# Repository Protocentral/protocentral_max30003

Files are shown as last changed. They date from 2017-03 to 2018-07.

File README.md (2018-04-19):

# ProtoCentral MAX30003 Single-lead ECG Breakout Board

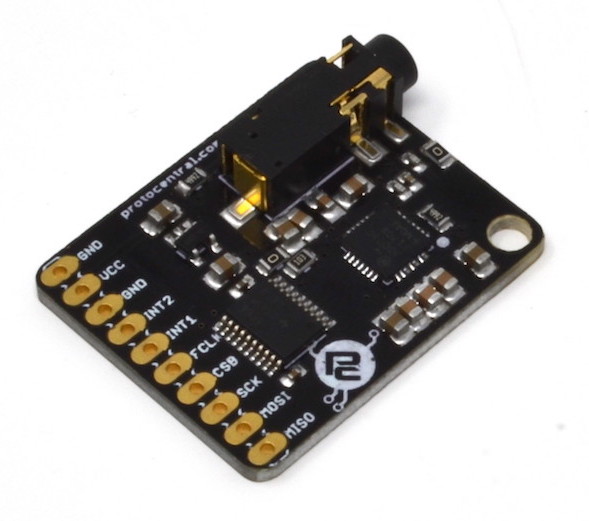
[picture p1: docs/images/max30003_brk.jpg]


If you dont already have one, you can buy [ProtoCentral MAX30003 breakout here.](https://www.protocentral.com/open-medical-devices/1149-protocentral-max30003-single-lead-ecg-breakout-board.html)

MAX30003 is a single-lead ECG monitoring IC which has built-in R-R detection and several other features that make it perfect for a wearable single-lead ECG application.  

Several new features on this chip make it ideal for wearable applications. First is the low power consumption - just 85 uW of power and can work from 1.1 V onwards ! Also of interest is the fact that it can work with only two chest electrodes without the need for a third right-leg drive (DRL) electrode.

The best feature of this chip though is the built-in R-R detection algorithm which can measure the time between successive peaks of the QRS complex of the ECG. This means that heart-computation comes right out of the box without any microcontroller-side code requirement. Heart-rate computation just got a lot easier !!

# Features

* MAX30003 IC on-board
* Single-lead ECG monitoring
* R-R peak detection for heart rate computation
* High DC Offset range
* Heart Rate computation using Pan-Tompkins algorithm
* On-board level translator for 5V-tolerant operation
* On-board low-noise 1.8V and 3.3V voltage regulator

# What's included

* ProtoCentral MAX30003 Breakout board
* Straight pin headers
* 2-electrode ECG connector with stereo connector
* 10x disposable ECG stick-on electrodes

# Repository Contents

* **/software** - Arduino library and example sketches.
* **/hardware** - All Eagle hardware design files
* **/docs** - additional documentation

# Wiring the board to your Arduino

If you have bought the breakout the connection with the Arduino board is as follows:

|MAX30003 pin label| Arduino Connection |Pin Function |
|--- |:---:|---:|
| MISO | D12 |  Slave out| 
| MOSI | D11 |  Slave in |
| SCK | D13 |  Serial clock |
| CS0 | D7 |  Slave select|
| FCLK | D6 |  External clock(32KHz) |
| INT1 | NC |  Interrupt |
| INT2 | NC |  Interrupt |
| 3V3 | Supply |  Board which supports 3.3V and 1.8V |
| VCC | Supply 5V | 5V |
| GND | Gnd  

# Running the Arduino Sketch

If you have correctly installed the libraries, the example sketeches should now be available from within Arduino.

[Download the Arduino Sketch here for this board here.](https://github.com/Protocentral/protocentral_max30003/releases/download/v0.1/protocentral_max30003_arduino.zip)

Open up your Arduino IDE and run the Arudino sketch (.ino) file in the archive that you downloaded. Your Arduino should now be programmed to read the ecg data and sending over the USB-UART.  

# Using the ProtoCentral MAX30003 GUI

The GUI for visulizing the ECG data as well as parameters like R-R interval and Heartrate is written in Processing, based on Java and is cross-compilable across platforms.

Java 8 is required on all platforms for running the processing-based GUI application. You can download Java for your platform from the following link.

[https://java.com/en/download/](https://java.com/en/download/)

## Processing GUI Installation

Download the zip file containing the executable files from the following links for 32-bit/64-bit Windows. If you do not know if you have a 64-bit or 32-bit computer, please download the 32-bit version.

* [Windows 32-bit Executable (ZIP)](https://github.com/Protocentral/protocentral_max30003/releases/download/v0.1/protocentral_max30003_gui-v0.1-win32.zip)
* [Windows 64-bit Executable (ZIP)](https://github.com/Protocentral/protocentral_max30003/releases/download/v0.1/protocentral_max30003_gui-v0.1-win64.zip/healthypi_gui_win64.zip)
* [MacOS Executable (ZIP)](https://github.com/Protocentral/protocentral_max30003/releases/download/v0.1/protocentral_max30003_gui-v0.1-macOS.zip)
* [Linux 32-bit Executable (ZIP)](https://github.com/Protocentral/protocentral_max30003/releases/download/v0.1/protocentral_max30003_gui-v0.1-linux32.zip)
* [Linux 64-bit Executable (ZIP)](https://github.com/Protocentral/protocentral_max30003/releases/download/v0.1/protocentral_max30003_gui-v0.1-linux64.zip)
* [Raspberry Pi - Raspbian (ZIP)](https://github.com/Protocentral/protocentral_max30003/releases/download/v0.1/protocentral_max30003_gui-v0.1-linuxARM.zip)

Simply download the appropriate file for your operating system, unzip the contents and run the executable program contained in it.

Select the port to which your Arduino is connected to from the "Select Port" dropdown box and data should immedaitely start coming in.

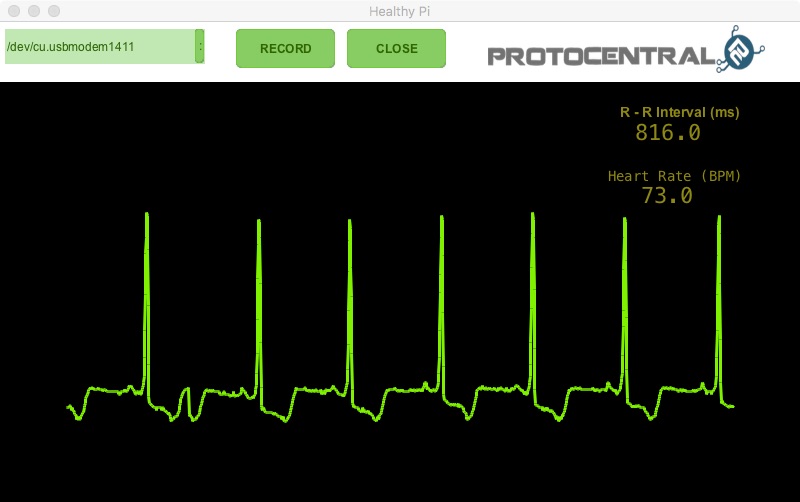
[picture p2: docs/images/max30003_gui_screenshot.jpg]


# Connecting the ECG Electrodes

A 2-electrode cable along with a standard stereo jack is provided along with the shield to connect the electrodes to the board. The electrode input connector is highlighted in the below picture.

The other side of the electrode connector would connect to snap-on electrodes attached to the body. For testing purposes, you can use an ECG simulator to provide inputs to the board.

*Warning:
When connecting the electodes to the body, it is safer to disconnect the mains power source to the Arduino. For example, if  you are using the Arduino along with a laptop, disconnecting the battery charger from the laptop would be a safe option.*

# Placing the Electrodes on the body

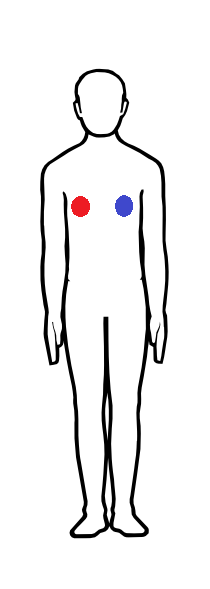
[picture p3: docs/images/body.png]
Wearing the Electrode


# License Information

This product is open source! Both, our hardware and software are open source and licensed under the following licenses:

## Hardware

**All hardware is released under [Creative Commons Share-alike 4.0 International](http://creativecommons.org/licenses/by-sa/4.0/).**


You are free to:

* Share — copy and redistribute the material in any medium or format
* Adapt — remix, transform, and build upon the material for any purpose, even commercially.
The licensor cannot revoke these freedoms as long as you follow the license terms.

Under the following terms:

* Attribution — You must give appropriate credit, provide a link to the license, and indicate if changes were made. You may do so in any reasonable manner, but not in any way that suggests the licensor endorses you or your use.
* ShareAlike — If you remix, transform, or build upon the material, you must distribute your contributions under the same license as the original.

## Software

**All software is released under the MIT License(http://opensource.org/licenses/MIT).**

THE SOFTWARE IS PROVIDED "AS IS", WITHOUT WARRANTY OF ANY KIND, EXPRESS OR IMPLIED, INCLUDING BUT NOT LIMITED TO THE WARRANTIES OF MERCHANTABILITY, FITNESS FOR A PARTICULAR PURPOSE AND NONINFRINGEMENT. IN NO EVENT SHALL THE AUTHORS OR COPYRIGHT HOLDERS BE LIABLE FOR ANY CLAIM, DAMAGES OR OTHER LIABILITY, WHETHER IN AN ACTION OF CONTRACT, TORT OR OTHERWISE, ARISING FROM, OUT OF OR IN CONNECTION WITH THE SOFTWARE OR THE USE OR OTHER DEALINGS IN THE SOFTWARE.

Please check [*LICENSE.md*](LICENSE.md) for detailed license descriptions.

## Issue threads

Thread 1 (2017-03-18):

Incorrect filter settings

protocentralashwin, 2017-03-18:
LPF, HPF filter settings to be updated

protocentralashwin, 2017-05-06:
Fixed

Closed 2017-05-06.

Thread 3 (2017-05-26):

Runing on arduino

ALEXRG27, 2017-05-26:
I'm trying to read the register with the value of the R_R , but I can't read anything, I get this :
ú            0,0,0,,0

     Serial.print(RTOR_msb);
     Serial.print(",");
     Serial.print(RTOR_lsb);
     Serial.print(",");
     Serial.print(rtor);
     Serial.print(",");
     //Serial.print(rr);
     Serial.print(",");
     Serial.println(HR);
How can I Read the ECG value from the arduino?
I also have a problem with the code, when i compile it says:
sketch\MAX30003.h:28:0: warning: "NO_OP" redefined

 #define   NO_OP           0x7F

 ^

sketch\MAX30003.h:9:0: note: this is the location of the previous definition

 #define   NO_OP           0x00

VenkateshBhat, 2017-05-27:
Dear Alex,

- Are you able to see the waveform on the gui?, could you attach the screenshot?
- If the data is clean these registers rr and HR will hold the corresponding values.
- NO_OP register doesn't have any impact on the operation, the warning can be ignored.
- Please ensure that you have the latest version of Arduino IDE

ALEXRG27, 2017-05-29:
No I can't see anything->
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

ALEXRG27, 2017-05-29:
If i disconect the board, i get this :
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
So the board i getting something but I don't know why i can't read the pulse

VenkateshBhat, 2017-05-29:
Thanks for sharing, are you sure about the wiring connections?,  do check with the latest version of Arduino IDE -- http://www.arduino.org/downloads

VenkateshBhat, 2017-05-29:
Please attach the picture of Hardware setup too.

ALEXRG27, 2017-06-07:
I've checked my board and all seems to be good. I used the same layout as you.

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

VenkateshBhat, 2017-06-21:
Have you made any progress on this?, it seems to be fuss in the assembly.

ALEXRG27, 2017-06-23:
No, I've tested the whole board and everything seems fine, i'll test it on my final design without the arduino I wish I could  read the data from the sensor.

DJMBurkhard, 2017-09-27:
Hello,
I have two questions:

1.) Connecting the max30003 board with Arduino Uno:
Should I use the 3V or the 5V?
I assume it is the one or the other?
And the power is supplied via the computer? (I am using a MAC)

2.) I cannot upload the sketch to Arduino
I receive the message:
fatal error: TimerOne.h: No such file or directory
#include <TimerOne.h>

Where can I find this file? It seems to be missing?
It is not in the folder,
I see the MAX30003.h  only -

DJMBurkhard, 2017-09-29:
Thanks for your previous respond which helped and could get:
The graph I receive now, using processing is the attached image
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

- the BPM are jumping around between 3 and 60, around 60, that would be correct, but it is jumping everywhere and:
- the graph is much different to what you show in the manual, see above image
-  the cvs file contains just one symbol - no data.
- I am told that the " protocentral_max30003_gui.app" is defect, and should take it to the trash.

Closed 2017-09-28.

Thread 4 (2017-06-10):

Analog voltage differences

fzldmn, 2017-06-10:
Hello in datasheet  recommended analog voltage is max 2V.
But in your design u used 3.3V

Will it be a problem for getting
 stable measurements.

VenkateshBhat, 2017-06-21:
Yes, the recommended power supply voltage is 1.1V - 2V , we tested for the long duration and there is no heating as such. We are getting the stable readings.

DJMBurkhard, 2017-09-27:
Hello,

1. Connecting the max30003 board with Arduino Uno:
    Should I use the 3V or the 5V?
    I assume it is one or the other? And the power is supplied via the computer (I am using a MAC)

2.   I cannot  upload the sketch to Arduino
    I receive the message:
   fatal error: TimerOne.h: No such file or directory
   #include <TimerOne.h>

    Where can I find this file? It seems to be missing.

VenkateshBhat, 2017-09-28:
@DJMBurkhard
1. Connect to 5V if you are using Arduino Uno.
2. Install the library externally for TimerOne.h
Go to sketch->Include libray -> Manage libraries
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

Closed 2017-10-09.

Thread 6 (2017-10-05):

BPM and Graphic with Processing strange

DJMBurkhard, 2017-10-05:
The graph I receive now, using processing is the attached image:
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

- the BPM are jumping around between 3 and 60, around 60, that would be correct, but it is jumping everywhere and:
- the graph is much different to what you show in the manual, see above image
-  the cvs file contains just one symbol - no data.
- I am told that the " protocentral_max30003_gui.app" is defect, and should take it to the trash.

VenkateshBhat, 2017-10-05:
@DJMBurkhard
Thanks for the feedback, the signal is too erratic.
ensure:
 > there is a good contact of electrodes on body
 > have a latest version of the Arduino(1.6.11 or above)
 >  Remove the power adapter from the PC/laptop and check

I will check on the no data on .csv file and get back to you.

DJMBurkhard, 2017-10-05:
Thank you -

So far, these issues are under control,
- I have the latest Arduino installed, 1.8.4,
- the electrodes are new and were placed as described,
- the power adapter was not plugged in while the trying to take measurement
( I am using a mac book air)
I am not aware of any other possible disturbing equipment
nearby:

In fact, before, I had taken measurements with another peace of equipment ,
"the pulse sensor", which is just wrapped around the finger.
That worked fine, as along as I was not moving.

But my hope is still in protocentral_max 30003, and I expect it to be more accurate.
However, as said before,  the BPM is mainly far too low,
at 3 to 30, rarely  around 60, which would be normal.

So, if you have any other idea, that would be much appreciated -

On 5. Oct 2017, at 16:16, Venkatesh Bhat <notifications@github.com> wrote:

@DJMBurkhard <https://github.com/djmburkhard>
Thanks for the feedback, the signal is too erratic.
ensure:

there is a good contact of electrodes on body
have a latest version of the Arduino(1.6.11 or above)
Remove the power adapter from the PC/laptop and check

I will check on the no data on .csv file and get back to you.

—
You are receiving this because you were mentioned.
Reply to this email directly, view it on GitHub <https://github.com/Protocentral/protocentral_max30003/issues/6#issuecomment-334478341>, or mute the thread <https://github.com/notifications/unsubscribe-auth/Ae2F-fV0dbb-21FV76LphRHGAeUkDdchks5spOSpgaJpZM4PupwZ>.

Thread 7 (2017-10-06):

Design

amir1994a, 2017-10-06:
In page 44 of the datasheet of max30003, in the recommended circuit it has used 1k resistor while you have
used 49.9k resistor? is this because of a particular reason? what will happen if you use a 1k resistor instead of 49.9k?

VenkateshBhat, 2017-10-07:
@amir1994a ,
the diagram mentioned in the datasheet is a typical application circuit not the recommended values.  The RC filter here acts as an anti-aliasing filter .Reference diagram is here https://www.maximintegrated.com/en/design/tools/appnotes/6312/MAXREFDES100_SCH_RA.pdf

amir1994a, 2017-10-07:
thank you, what about the zero value resistor?is it going to be a problem if we don't use them?

VenkateshBhat, 2017-10-07:
No, it does not affect the performance.

Tomisdebom, 2021-09-13:
> @amir1994a ,
> the diagram mentioned in the datasheet is a typical application circuit not the recommended values. The RC filter here acts as an anti-aliasing filter .Reference diagram is here https://www.maximintegrated.com/en/design/tools/appnotes/6312/MAXREFDES100_SCH_RA.pdf

Wait, the reference design you just posted is different than the schematics that are in the Github repo. Are you sure your reference design corresponds to the Protocentral board?

Closed 2017-10-09.

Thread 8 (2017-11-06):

A question about the external clock

amir1994a, 2017-11-06:
Hi, I've been trying to understand the board and the code, I'm confused a little bit.
How do you produce the external clock?it seems that there is no crystal or oscillator on the board.
what is this line for?:
    digitalWrite( CLK_PIN, digitalRead(CLK_PIN ) ^ 1 ); // toggle Digital6 attached to FCLK  of MAX30003

why do toggle the fclk pin?

VenkateshBhat, 2017-11-06:
@amir1994a
Thanks for the comment,
Since Arduino doesnot have internal RTC we are deriving using the timer with 64KHz clock frequency and toggling a GPIO.

amir1994a, 2017-11-06:
Thank you for your answer, at first my code(yours actually) wouldn't compile because of the lack of time1 library, i downloaded it from this link(9th version) and it compiled without error, is that the right procedure?

one more question, actually, i did not use your board because i couldn't find it in my country, so i tried to use your schematic and make it myself. only i did not use 0-ohm resistors. and i did not use ground plane(except for the ic pad). and i used this voltage converter:

https://www.sparkfun.com/products/12009

my board did not work, i assumed that maybe this voltage converter is not good for spi connection and maybe 5 and 1.8 have a lot difference for my voltage converter.
I'm really frustrated and i know that only you can help me.
will you please help me a little bit?
(also the ac line frequency is 50hz in my country and is different from 60hz of some countries i don't know that this will cause any problem or not)

Thanks a million
please help me!!!

VenkateshBhat, 2017-11-07:
@amir1994a ,
Do not worry we are here to help you out!
Could you please share your design? what signal are you getting at the output? FCLK is critical are you sure about the signal? the level converter could not be the problem, BSS138 is good enough.

amir1994a, 2017-11-07:
Hi, thank you, you are so kind.
Actually, I get no signal at the output.
I have attached a pdf file of my schematic and PCB, I'll be grateful f you check it out. it is a little bit messy!
Can you explain a little bit about TimerOne library?, because arduino does not seem to have this library by default.
I'll be thankful if you tell me what my problem is.
[heart.PDF](https://github.com/Protocentral/protocentral_max30003/files/1448888/heart.PDF)

amir1994a, 2017-11-12:
Hi there,
I was wondering whether you had the time to look at my previous question.
I'm enthusiastically looking forward to hearing from you

protocentralashwin, 2018-04-06:
Merging this with issue #13

Closed 2018-04-06.

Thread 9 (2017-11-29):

Ecg circuit

amir1994a, 2017-11-29:
Hi there,
I've been trying to get a response from my board which I designed using your schematics in the past month.I'm afraid I cannot get any signal in the output. My filter is like your filter in your schematic except i'm using 47k resistor instead of 49.9k of yours.

The datasheet says that the ic has a 1v on the vref pin but I cannot get such value on my board.
Will you please check vref of your board and inform me if you get the 1 volt? As you know vref voltage can be measured by measureing the voltage over the 10uf capacitor it is connected to.

If you help me a little bit,I'll be forever thankful.

Thank you very much
Best regards,
Safaei

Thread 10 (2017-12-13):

No ECG signal

stanky95, 2017-12-13:
Hi,
I have bought a protocentral breakout board for MAX30003 recently and I have been struggling to get it up and running. A similar issue is occuring to me as the one that can be found on the link below:

https://github.com/Protocentral/protocentral_max30003/issues/6

I'm running an Arduino Leonardo with the latest Arduino IDE version. I have tried several versions from the your github repository with no substantial difference. I have wired everything according to your schematic, except for the MISO/MOSI/SCK pins, which are wired to the ICSP header since Leonardo has SPI pins available only there, as far as I know. I am also using the provided cable and electrodes. Everything is connected via usb to the laptop disconnected from the mains.

I have also detected that it is not an issue in the GUI, since I have tried bypassing it by printing to serial only the ECG data, and not the whole data header, and monitoring it with Serial Plotter - with the same result present.

(just to clarify, I am basically using this:
Serial.println(ecgdata);
instead of the for loop for printing to the serial)

Do you have any clue what might be happening?

VenkateshBhat, 2017-12-14:
@stanky95
Try out this code and let me know. I have changed the FCLK pin to a dedicated PWM pin.
Connect the FCLK to digital 9 of Lenardo rest all pins are the same.

[test.txt](https://github.com/Protocentral/protocentral_max30003/files/1557999/test.txt)

stanky95, 2017-12-14:
@VenkateshBhat
I have tried the code you provided and swapped the pins:
When using this code, the output is completely constant, usually at zero. It does not matter if leads are connected or not.

I presume that it might have to do with the FCLK? Since the original code was driving the FCLK pin every 16us, which means the period is 32us, which gives a frequency of 31250 Hz, while it is specified in the MAX30003 datasheet that the frequency should be 32768 Hz. I'm not sure why it doesn't work with the PWM.

VenkateshBhat, 2017-12-14:
Something is wrong here, it doesn't give a flat line.  I checked with the Lenardo board and it is working fine for me with PWM.
Yes the clock should be 32.768KHz, since we can not generate exact clock using the timer prescalar we are using clock close to that.
kindly share your connection setup and arduino sketch.

AliAlzuabi, 2023-09-02:
I have a question, what did you use guys to generate FCLK = 32768Hz for Maz30003 ?

protocentralashwin, 2023-09-02:
Hi @AliAlzuabi , in the latest versions of the boards, 32 KHz clock is generated by a onboard CMOS oscillator and that works fine. So you do not have to generate a separate clock for this.

AliAlzuabi, 2023-09-02:
Hello @protocentralashwin, are you suggesting that if I've used an ESP32 Dev module, and it has generated an FCLK of 32Khz, can this be worked as FCLK for the Max30003? No need for external crystal ?

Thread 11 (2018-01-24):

Noisy data and unclear .csv readings.

rogzam, 2018-01-24:
Hello,

I've acquired your max30003 module and hooked up to an Arduino Uno and after several iterations I managed to get a decent Heart Rate signal. However:

Even though I've followed your instructions carefully the data is still really noisy,  I've tried several positions for the electrodes, staying still, unplugged everything else from the laptop (I found out that my HDMI monitor and laptop charger were inducing a lot of noise to the signal), etc. Is there any way to get a cleaner data? Something similar to what you present in your webpage?.. This is my cleanest reading so far:

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

Another thing that it's not fully clear to me is the wiring. Here you say that the module has a 3.3v pin, a 5v and a GND:

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

However, the product says GND - VCC - GND, so, which one is it? Should I plug both pins to the ground? should I plug one to 5v, one to 3.3v and the last one to GND? or just 5v and GND and leave the last one unplugged?

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

Lastly, once I open the raw data I get these columns:

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

Can you please explain what do they mean? what are they measuring and what scale are there using? I understand that the first one is the timestamp, but, ECG?, SpO2?, respiration?

I'm attaching the .csv ->
[log.csv.zip](https://github.com/Protocentral/protocentral_max30003/files/1660201/log.csv.zip)

Thanks for your help.

rogzam, 2018-01-31:
@VenkateshBhat, @protocentralashwin ... Any comments, ideas?

protocentralashwin, 2018-02-01:
@rogzam I'm sorry about the wrong documentation. Earlier we had 3v3 and VCC separately, but now we combined both together in the new version of the board, so the other pin is not connected to power, you can leave it unconnected or to ground.

As for the noise, It depends on a lot of things. Since this is only 2-electrode measurement, there is no third electrode for noise compensation. I would mainly check the power supply to make sure it is stable. What source are you using to power the board? Also, the electrodes cables and contact would be important. Please keep in mind that this IC was designed for wearable applications and you would get best results from a battery operated system.

As for the log file, I think the example code has some extra fields that we were using for testing, you can ignore those. We will correct the code.

rogzam, 2018-02-02:
@protocentralashwin Thanks for your answer.

I'm using a Lipo Battery to power the device and have tested different positions for the electrodes being the one recorded on the log I attached the cleanest one. Any recommendations in order to get a signal as clean as the one pictured on your webpage?

Also, can you give me a little more information on the data recorded on the csv?.  What's the unit of what is being shown on the file?

Thanks.

rogzam, 2018-02-07:
@VenkateshBhat, @protocentralashwin ?

iharshadec, 2018-02-23:
I am also seeing so much noise and signal is not as clear as shown on webpage. I am running board via Battery Only.

protocentralashwin, 2018-04-06:
@rogzam @iharshadec  Can you try powering the board separately through a battery? A bad arduino with which has a ground in common with the device can add noise. Since this is a 2-electrode ECG without a driven right leg (DRL), there is no way to drive back the common mode.

amir1994a, 2018-05-17:
@rogzam @iharshadec  were you able to fix your problem? I'm facing a noisy signal too...

iharshadec, 2018-05-17:
@amir1994a :
No, I am not able to get it even with separate battery.

amir1994a, 2018-05-17:
@iharshadec
Are you using your own board? or the protocentral module?

rogzam, 2018-05-17:
@amir1994a @iharshadec I managed to make it work. I have the module working with a Nano and a Lipo. I found out that my monitor's power brick was causing some of the noise. Once I stepped away from the monitor I got a cleaner signal. However, is nothing like the one shown on Protocentral's video... Still disappointed of their product and they total lack of communication.

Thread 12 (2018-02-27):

Max30003 problem with SPI

adelalfusail, 2018-02-27:
Hi, my project is patient Monitor I already bought max30003,afe4490,max3025 and I'm trying collect them in one arduino(mega 2025),everything is ok except when I'm connect SPI pins for max30003 and afe4490 the date is confuse  or maybe the is lost for max 30003 I have been trying to fix this problem almost two months and no response .
I just need to what is the problem.
 notice :the main problem is when I connect miso for both device

georod99, 2018-04-05:
Hi, I'm a retired physics teacher, thou I worked in the physics labs at Havana University for many years.
Could you make the Max30003 work? I haven't. Can you post pictures of what you did?
I'm trying to get HRV real-time. What is your objective?
More after you answer. Thanks.

protocentralashwin, 2018-04-06:
@adelalfusail Please make sure that the CS lines are separate and only one device is selected at a time when the SPI bus is used.

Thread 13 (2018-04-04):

Single-lead ECG monitor

georod99, 2018-04-04:
I have followed all the instructions and I get an error when compiling the sketch:
1. This is the error:

C:\Program Files\WindowsApps\ArduinoLLC.ArduinoIDE_1.8.10.0_x86__mdqgnx93n4wtt\arduino-builder -dump-prefs -logger=machine -hardware C:\Program Files\WindowsApps\ArduinoLLC.ArduinoIDE_1.8.10.0_x86__mdqgnx93n4wtt\hardware -tools C:\Program Files\WindowsApps\ArduinoLLC.ArduinoIDE_1.8.10.0_x86__mdqgnx93n4wtt\tools-builder -tools C:\Program Files\WindowsApps\ArduinoLLC.ArduinoIDE_1.8.10.0_x86__mdqgnx93n4wtt\hardware\tools\avr -built-in-libraries C:\Program Files\WindowsApps\ArduinoLLC.ArduinoIDE_1.8.10.0_x86__mdqgnx93n4wtt\libraries -libraries C:\Users\georo\Documents\Arduino\libraries -fqbn=arduino:avr:uno -vid-pid=0X2341_0X0043 -ide-version=10805 -build-path C:\Users\georo\AppData\Local\Temp\arduino_build_914942 -warnings=default -build-cache C:\Users\georo\AppData\Local\Temp\arduino_cache_78938 -prefs=build.warn_data_percentage=75 -prefs=runtime.tools.arduinoOTA.path=C:\Program Files\WindowsApps\ArduinoLLC.ArduinoIDE_1.8.10.0_x86__mdqgnx93n4wtt\hardware\tools\avr -prefs=runtime.tools.avr-gcc.path=C:\Program Files\WindowsApps\ArduinoLLC.ArduinoIDE_1.8.10.0_x86__mdqgnx93n4wtt\hardware\tools\avr -prefs=runtime.tools.avrdude.path=C:\Program Files\WindowsApps\ArduinoLLC.ArduinoIDE_1.8.10.0_x86__mdqgnx93n4wtt\hardware\tools\avr -verbose C:\Users\georo\AppData\Local\Temp\Temp2_protocentral_max30003_arduino.zip\protocentral_max30003_arduino\protocentral_max30003\protocentral_max30003.ino
C:\Program Files\WindowsApps\ArduinoLLC.ArduinoIDE_1.8.10.0_x86__mdqgnx93n4wtt\arduino-builder -compile -logger=machine -hardware C:\Program Files\WindowsApps\ArduinoLLC.ArduinoIDE_1.8.10.0_x86__mdqgnx93n4wtt\hardware -tools C:\Program Files\WindowsApps\ArduinoLLC.ArduinoIDE_1.8.10.0_x86__mdqgnx93n4wtt\tools-builder -tools C:\Program Files\WindowsApps\ArduinoLLC.ArduinoIDE_1.8.10.0_x86__mdqgnx93n4wtt\hardware\tools\avr -built-in-libraries C:\Program Files\WindowsApps\ArduinoLLC.ArduinoIDE_1.8.10.0_x86__mdqgnx93n4wtt\libraries -libraries C:\Users\georo\Documents\Arduino\libraries -fqbn=arduino:avr:uno -vid-pid=0X2341_0X0043 -ide-version=10805 -build-path C:\Users\georo\AppData\Local\Temp\arduino_build_914942 -warnings=default -build-cache C:\Users\georo\AppData\Local\Temp\arduino_cache_78938 -prefs=build.warn_data_percentage=75 -prefs=runtime.tools.arduinoOTA.path=C:\Program Files\WindowsApps\ArduinoLLC.ArduinoIDE_1.8.10.0_x86__mdqgnx93n4wtt\hardware\tools\avr -prefs=runtime.tools.avr-gcc.path=C:\Program Files\WindowsApps\ArduinoLLC.ArduinoIDE_1.8.10.0_x86__mdqgnx93n4wtt\hardware\tools\avr -prefs=runtime.tools.avrdude.path=C:\Program Files\WindowsApps\ArduinoLLC.ArduinoIDE_1.8.10.0_x86__mdqgnx93n4wtt\hardware\tools\avr -verbose C:\Users\georo\AppData\Local\Temp\Temp2_protocentral_max30003_arduino.zip\protocentral_max30003_arduino\protocentral_max30003\protocentral_max30003.ino
Using board 'uno' from platform in folder: C:\Program Files\WindowsApps\ArduinoLLC.ArduinoIDE_1.8.10.0_x86__mdqgnx93n4wtt\hardware\arduino\avr
Using core 'arduino' from platform in folder: C:\Program Files\WindowsApps\ArduinoLLC.ArduinoIDE_1.8.10.0_x86__mdqgnx93n4wtt\hardware\arduino\avr
Detecting libraries used...
"C:\Program Files\WindowsApps\ArduinoLLC.ArduinoIDE_1.8.10.0_x86__mdqgnx93n4wtt\hardware\tools\avr/bin/avr-g++" -c -g -Os -w -std=gnu++11 -fpermissive -fno-exceptions -ffunction-sections -fdata-sections -fno-threadsafe-statics  -flto -w -x c++ -E -CC -mmcu=atmega328p -DF_CPU=16000000L -DARDUINO=10805 -DARDUINO_AVR_UNO -DARDUINO_ARCH_AVR   "-IC:\Program Files\WindowsApps\ArduinoLLC.ArduinoIDE_1.8.10.0_x86__mdqgnx93n4wtt\hardware\arduino\avr\cores\arduino" "-IC:\Program Files\WindowsApps\ArduinoLLC.ArduinoIDE_1.8.10.0_x86__mdqgnx93n4wtt\hardware\arduino\avr\variants\standard" "C:\Users\georo\AppData\Local\Temp\arduino_build_914942\sketch\protocentral_max30003.ino.cpp" -o "nul"
"C:\Program Files\WindowsApps\ArduinoLLC.ArduinoIDE_1.8.10.0_x86__mdqgnx93n4wtt\hardware\tools\avr/bin/avr-g++" -c -g -Os -w -std=gnu++11 -fpermissive -fno-exceptions -ffunction-sections -fdata-sections -fno-threadsafe-statics  -flto -w -x c++ -E -CC -mmcu=atmega328p -DF_CPU=16000000L -DARDUINO=10805 -DARDUINO_AVR_UNO -DARDUINO_ARCH_AVR   "-IC:\Program Files\WindowsApps\ArduinoLLC.ArduinoIDE_1.8.10.0_x86__mdqgnx93n4wtt\hardware\arduino\avr\cores\arduino" "-IC:\Program Files\WindowsApps\ArduinoLLC.ArduinoIDE_1.8.10.0_x86__mdqgnx93n4wtt\hardware\arduino\avr\variants\standard" "-IC:\Program Files\WindowsApps\ArduinoLLC.ArduinoIDE_1.8.10.0_x86__mdqgnx93n4wtt\hardware\arduino\avr\libraries\SPI\src" "C:\Users\georo\AppData\Local\Temp\arduino_build_914942\sketch\protocentral_max30003.ino.cpp" -o "nul"
"C:\Program Files\WindowsApps\ArduinoLLC.ArduinoIDE_1.8.10.0_x86__mdqgnx93n4wtt\hardware\tools\avr/bin/avr-g++" -c -g -Os -w -std=gnu++11 -fpermissive -fno-exceptions -ffunction-sections -fdata-sections -fno-threadsafe-statics  -flto -w -x c++ -E -CC -mmcu=atmega328p -DF_CPU=16000000L -DARDUINO=10805 -DARDUINO_AVR_UNO -DARDUINO_ARCH_AVR   "-IC:\Program Files\WindowsApps\ArduinoLLC.ArduinoIDE_1.8.10.0_x86__mdqgnx93n4wtt\hardware\arduino\avr\cores\arduino" "-IC:\Program Files\WindowsApps\ArduinoLLC.ArduinoIDE_1.8.10.0_x86__mdqgnx93n4wtt\hardware\arduino\avr\variants\standard" "-IC:\Program Files\WindowsApps\ArduinoLLC.ArduinoIDE_1.8.10.0_x86__mdqgnx93n4wtt\hardware\arduino\avr\libraries\SPI\src" "-IC:\Users\georo\Documents\Arduino\libraries\TimerOne" "C:\Users\georo\AppData\Local\Temp\arduino_build_914942\sketch\protocentral_max30003.ino.cpp" -o "nul"
"C:\Program Files\WindowsApps\ArduinoLLC.ArduinoIDE_1.8.10.0_x86__mdqgnx93n4wtt\hardware\tools\avr/bin/avr-g++" -c -g -Os -w -std=gnu++11 -fpermissive -fno-exceptions -ffunction-sections -fdata-sections -fno-threadsafe-statics  -flto -w -x c++ -E -CC -mmcu=atmega328p -DF_CPU=16000000L -DARDUINO=10805 -DARDUINO_AVR_UNO -DARDUINO_ARCH_AVR   "-IC:\Program Files\WindowsApps\ArduinoLLC.ArduinoIDE_1.8.10.0_x86__mdqgnx93n4wtt\hardware\arduino\avr\cores\arduino" "-IC:\Program Files\WindowsApps\ArduinoLLC.ArduinoIDE_1.8.10.0_x86__mdqgnx93n4wtt\hardware\arduino\avr\variants\standard" "-IC:\Program Files\WindowsApps\ArduinoLLC.ArduinoIDE_1.8.10.0_x86__mdqgnx93n4wtt\hardware\arduino\avr\libraries\SPI\src" "-IC:\Users\georo\Documents\Arduino\libraries\TimerOne" "C:\Users\georo\AppData\Local\Temp\arduino_build_914942\sketch\protocentral_max30003.ino.cpp" -o "C:\Users\georo\AppData\Local\Temp\arduino_build_914942\preproc\ctags_target_for_gcc_minus_e.cpp"
C:\Users\georo\AppData\Local\Temp\Temp2_protocentral_max30003_arduino.zip\protocentral_max30003_arduino\protocentral_max30003\protocentral_max30003.ino:3:22: fatal error: MAX30003.h: No such file or directory

 #include "MAX30003.h"

                      ^

compilation terminated.

Using library SPI at version 1.0 in folder: C:\Program Files\WindowsApps\ArduinoLLC.ArduinoIDE_1.8.10.0_x86__mdqgnx93n4wtt\hardware\arduino\avr\libraries\SPI
Using library TimerOne at version 1.1 in folder: C:\Users\georo\Documents\Arduino\libraries\TimerOne
exit status 1
Error compiling for board Arduino/Genuino Uno.

2. This is the sketch:
#include<SPI.h>
#include <TimerOne.h>
#include "MAX30003.h"

#define MAX30003_CS_PIN   7
#define CLK_PIN          6

volatile char SPI_RX_Buff[5] ;
volatile char *SPI_RX_Buff_Ptr;
int i=0;
unsigned long uintECGraw = 0;
signed long intECGraw=0;
uint8_t DataPacketHeader[20];
uint8_t data_len = 8;
 signed long ecgdata;
 unsigned long data;

char SPI_temp_32b[4];
char SPI_temp_Burst[100];

// 32KHz clock using timer1
void timerIsr()
{
    digitalWrite( CLK_PIN, digitalRead(CLK_PIN ) ^ 1 ); // toggle Digital6 attached to FCLK  of MAX30003
}

void setup()
{
    Serial.begin(115200); //Serial begin

    pinMode(MAX30003_CS_PIN,OUTPUT);
    digitalWrite(MAX30003_CS_PIN,HIGH); //disable device

    SPI.begin();
    SPI.setBitOrder(MSBFIRST);
    SPI.setDataMode(SPI_MODE0);
    SPI.setClockDivider(SPI_CLOCK_DIV4);

    pinMode(CLK_PIN,OUTPUT);

    MAX30003_begin();   // initialize MAX30003

}

void loop()
{
    MAX30003_Reg_Read(ECG_FIFO);

    unsigned long data0 = (unsigned long) (SPI_temp_32b[0]);
    data0 = data0 <<24;
    unsigned long data1 = (unsigned long) (SPI_temp_32b[1]);
    data1 = data1 <<16;
    unsigned long data2 = (unsigned long) (SPI_temp_32b[2]);
    data2 = data2 >>6;
    data2 = data2 & 0x03;

    data = (unsigned long) (data0 | data1 | data2);
    ecgdata = (signed long) (data);

    MAX30003_Reg_Read(RTOR);
    unsigned long RTOR_msb = (unsigned long) (SPI_temp_32b[0]);
   // RTOR_msb = RTOR_msb <<8;
    unsigned char RTOR_lsb = (unsigned char) (SPI_temp_32b[1]);

    unsigned long rtor = (RTOR_msb<<8 | RTOR_lsb);
    rtor = ((rtor >>2) & 0x3fff) ;

    float hr =  60 /((float)rtor*0.008);
   unsigned int HR = (unsigned int)hr;  // type cast to int

    unsigned int RR = (unsigned int)rtor*8 ;  //8ms

     /*Serial.print(RTOR_msb);
     Serial.print(",");
     Serial.print(RTOR_lsb);
     Serial.print(",");
     Serial.print(rtor);
     Serial.print(",");
     Serial.print(rr);
     Serial.print(",");
     Serial.println(hr);      */

      DataPacketHeader[0] = 0x0A;
      DataPacketHeader[1] = 0xFA;
      DataPacketHeader[2] = 0x0C;
      DataPacketHeader[3] = 0;
      DataPacketHeader[4] = 0x02;

      DataPacketHeader[5] = ecgdata;
      DataPacketHeader[6] = ecgdata>>8;
      DataPacketHeader[7] = ecgdata>>16;
      DataPacketHeader[8] = ecgdata>>24;

      DataPacketHeader[9] =  RR ;
      DataPacketHeader[10] = RR >>8;
      DataPacketHeader[11] = 0x00;
      DataPacketHeader[12] = 0x00;

      DataPacketHeader[13] = HR ;
      DataPacketHeader[14] = HR >>8;
      DataPacketHeader[15] = 0x00;
      DataPacketHeader[16] = 0x00;

      DataPacketHeader[17] = 0x00;
      DataPacketHeader[18] = 0x0b;

      for(i=0; i<19; i++) // transmit the data
      {
        Serial.write(DataPacketHeader[i]);

       }

    delay(1);
}

void MAX30003_Reg_Write (unsigned char WRITE_ADDRESS, unsigned long data)
{

  // now combine the register address and the command into one byte:
   byte dataToSend = (WRITE_ADDRESS<<1) | WREG;

   // take the chip select low to select the device:
   digitalWrite(MAX30003_CS_PIN, LOW);

   delay(2);
   SPI.transfer(dataToSend);   //Send register location
   SPI.transfer(data>>16);     //number of register to wr
   SPI.transfer(data>>8);      //number of register to wr
   SPI.transfer(data);      //Send value to record into register
   delay(2);

   // take the chip select high to de-select:
   digitalWrite(MAX30003_CS_PIN, HIGH);
}

void max30003_sw_reset(void)
{
  MAX30003_Reg_Write(SW_RST,0x000000);
  delay(100);
}

void max30003_synch(void)
{
  MAX30003_Reg_Write(SYNCH,0x000000);
}

void MAX30003_Reg_Read(uint8_t Reg_address)
{
   uint8_t SPI_TX_Buff;

   digitalWrite(MAX30003_CS_PIN, LOW);

   SPI_TX_Buff = (Reg_address<<1 ) | RREG;
   SPI.transfer(SPI_TX_Buff); //Send register location

   for ( i = 0; i < 3; i++)
   {
      SPI_temp_32b[i] = SPI.transfer(0xff);
   }

   digitalWrite(MAX30003_CS_PIN, HIGH);
}

void MAX30003_Read_Data(int num_samples)
{
  uint8_t SPI_TX_Buff;

  digitalWrite(MAX30003_CS_PIN, LOW);

  SPI_TX_Buff = (ECG_FIFO_BURST<<1 ) | RREG;
  SPI.transfer(SPI_TX_Buff); //Send register location

  for ( i = 0; i < num_samples*3; ++i)
  {
    SPI_temp_Burst[i] = SPI.transfer(0x00);
  }

  digitalWrite(MAX30003_CS_PIN, HIGH);
}
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
protocentralashwin, 2018-04-06:
Hello @georod99 This because you haven't installed the TimerOne library available in the Arduino libraries page.

Just go to Sketch->Include Library->Manage Libraries and search for "TimerOne' and install it. Let me know if there's still a problem.

Closed 2018-05-27.

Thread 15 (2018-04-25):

Serial Plotter shows nothing Max30003

georod99, 2018-04-25:
This is the code (compiles and runs OK):
Loaded in Arduino 1.8.4.
// I put max30003.h inside protocentral max

#include<SPI.h>
#include <TimerOne.h>
#include "MAX30003.h"

#define MAX30003_CS_PIN   7
#define CLK_PIN          6

volatile char SPI_RX_Buff[5] ;
volatile char *SPI_RX_Buff_Ptr;
int i=0;
unsigned long uintECGraw = 0;
signed long intECGraw=0;
uint8_t DataPacketHeader[20];
uint8_t data_len = 8;
 signed long ecgdata;
 unsigned long data;

char SPI_temp_32b[4];
char SPI_temp_Burst[100];

// 32KHz clock using timer1
void timerIsr()
{
    digitalWrite( CLK_PIN, digitalRead(CLK_PIN ) ^ 1 ); // toggle Digital6 attached to FCLK  of MAX30003
}

void setup()
{
    Serial.begin(115200); //Serial begin

    pinMode(MAX30003_CS_PIN,OUTPUT);
    digitalWrite(MAX30003_CS_PIN,HIGH); //disable device

    SPI.begin();
    SPI.setBitOrder(MSBFIRST);
    SPI.setDataMode(SPI_MODE0);
    SPI.setClockDivider(SPI_CLOCK_DIV4);

    pinMode(CLK_PIN,OUTPUT);

    MAX30003_begin();   // initialize MAX30003

}

void loop()
{
    MAX30003_Reg_Read(ECG_FIFO);

    unsigned long data0 = (unsigned long) (SPI_temp_32b[0]);
    data0 = data0 <<24;
    unsigned long data1 = (unsigned long) (SPI_temp_32b[1]);
    data1 = data1 <<16;
    unsigned long data2 = (unsigned long) (SPI_temp_32b[2]);
    data2 = data2 >>6;
    data2 = data2 & 0x03;

    data = (unsigned long) (data0 | data1 | data2);
    ecgdata = (signed long) (data);

    MAX30003_Reg_Read(RTOR);
    unsigned long RTOR_msb = (unsigned long) (SPI_temp_32b[0]);
   // RTOR_msb = RTOR_msb <<8;
    unsigned char RTOR_lsb = (unsigned char) (SPI_temp_32b[1]);

    unsigned long rtor = (RTOR_msb<<8 | RTOR_lsb);
    rtor = ((rtor >>2) & 0x3fff) ;

    float hr =  60 /((float)rtor*0.008);
   unsigned int HR = (unsigned int)hr;  // type cast to int

    unsigned int RR = (unsigned int)rtor*8 ;  //8ms

     /*Serial.print(RTOR_msb);
     Serial.print(",");
     Serial.print(RTOR_lsb);
     Serial.print(",");
     Serial.print(rtor);
     Serial.print(",");
     Serial.print(rr);
     Serial.print(",");
     Serial.println(hr);      */

      DataPacketHeader[0] = 0x0A;
      DataPacketHeader[1] = 0xFA;
      DataPacketHeader[2] = 0x0C;
      DataPacketHeader[3] = 0;
      DataPacketHeader[4] = 0x02;

      DataPacketHeader[5] = ecgdata;
      DataPacketHeader[6] = ecgdata>>8;
      DataPacketHeader[7] = ecgdata>>16;
      DataPacketHeader[8] = ecgdata>>24;

      DataPacketHeader[9] =  RR ;
      DataPacketHeader[10] = RR >>8;
      DataPacketHeader[11] = 0x00;
      DataPacketHeader[12] = 0x00;

      DataPacketHeader[13] = HR ;
      DataPacketHeader[14] = HR >>8;
      DataPacketHeader[15] = 0x00;
      DataPacketHeader[16] = 0x00;

      DataPacketHeader[17] = 0x00;
      DataPacketHeader[18] = 0x0b;

      for(i=0; i<19; i++) // transmit the data
      {
        Serial.write(DataPacketHeader[i]);

       }

    delay(1);
}

void MAX30003_Reg_Write (unsigned char WRITE_ADDRESS, unsigned long data)
{

  // now combine the register address and the command into one byte:
   byte dataToSend = (WRITE_ADDRESS<<1) | WREG;

   // take the chip select low to select the device:
   digitalWrite(MAX30003_CS_PIN, LOW);

   delay(2);
   SPI.transfer(dataToSend);   //Send register location
   SPI.transfer(data>>16);     //number of register to wr
   SPI.transfer(data>>8);      //number of register to wr
   SPI.transfer(data);      //Send value to record into register
   delay(2);

   // take the chip select high to de-select:
   digitalWrite(MAX30003_CS_PIN, HIGH);
}

void max30003_sw_reset(void)
{
  MAX30003_Reg_Write(SW_RST,0x000000);
  delay(100);
}

void max30003_synch(void)
{
  MAX30003_Reg_Write(SYNCH,0x000000);
}

void MAX30003_Reg_Read(uint8_t Reg_address)
{
   uint8_t SPI_TX_Buff;

   digitalWrite(MAX30003_CS_PIN, LOW);

   SPI_TX_Buff = (Reg_address<<1 ) | RREG;
   SPI.transfer(SPI_TX_Buff); //Send register location

   for ( i = 0; i < 3; i++)
   {
      SPI_temp_32b[i] = SPI.transfer(0xff);
   }

   digitalWrite(MAX30003_CS_PIN, HIGH);
}

void MAX30003_Read_Data(int num_samples)
{
  uint8_t SPI_TX_Buff;

  digitalWrite(MAX30003_CS_PIN, LOW);

  SPI_TX_Buff = (ECG_FIFO_BURST<<1 ) | RREG;
  SPI.transfer(SPI_TX_Buff); //Send register location

  for ( i = 0; i < num_samples*3; ++i)
  {
    SPI_temp_Burst[i] = SPI.transfer(0x00);
  }

  digitalWrite(MAX30003_CS_PIN, HIGH);
}

void MAX30003_begin()
{
    //Start CLK timer
    Timer1.initialize(16);              // set a timer of length 100000 microseconds (or 0.1 sec - or 10Hz => the led will blink 5 times, 5 cycles of on-and-off, per second)
    Timer1.attachInterrupt( timerIsr ); // attach the service routine here

    max30003_sw_reset();
    delay(100);
    MAX30003_Reg_Write(CNFG_GEN, 0x081007);
    delay(100);
    MAX30003_Reg_Write(CNFG_CAL, 0x720000);  // 0x700000
    delay(100);
    MAX30003_Reg_Write(CNFG_EMUX,0x0B0000);
    delay(100);
    MAX30003_Reg_Write(CNFG_ECG, 0x005000);  // d23 - d22 : 10 for 250sps , 00:500 sps
    delay(100);

    MAX30003_Reg_Write(CNFG_RTOR1,0x3fc600);
    max30003_synch();
    delay(100);
}

adelalfusail, 2018-05-10:
serial ploter will show nothing, if you want to show ecg signal you need to use gui

Closed 2018-05-27.

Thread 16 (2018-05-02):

Bad signal and unit question?

PaginaRice, 2018-05-02:
Hello protocentral community,
I have been working on a project using the MAX30003 for several weeks now. Our signal is very unclear, (see attached image). Additionally, I am struggling to use the .csv file to troubleshoot because I don't know what the units are for the ecg data, and  the "timestamp" column is showing the same time for every single datapoint.

Does anyone have any insight on how to improve our signal and what the output data even means (units-wise)? Lastly, I noticed on the datasheet that it said filtering was an option, does that mean we have to opt to turn it on or off somewhere within the code?

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

Any help would be greatly appreciated!
Thanks!

adelalfusail, 2018-05-10:
there is some reasons you need to check:
 1-you need to make sure to pin connection
2-you need to discharge computer from charger
3-stay far from power source 60/120 HZ

amir1994a, 2018-05-17:
@PaginaRice Hi, I'm facing the same problem for a long time! Have you been able to fix it?

adelalfusail, 2018-07-14:
Can you explain more to understand your problem????

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

joicetm, 2018-10-05:
are you able to fix it?
if not, you try with the latest [commit](https://github.com/Protocentral/protocentral_max30003)

joicetm, 2018-11-24:
Hi,
I am closing this issue for now, please feel free to open if its not fixed.

Closed 2018-11-24.

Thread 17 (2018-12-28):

MAX30003 calibration and leads-off detection

francescolavra, 2018-12-28:
I'm developing an application using the ProtoCentral MAX30003 breakout board.
Trying to use the leads-off detection functionality, I found that MAX30003 does not detect a leads-off condition if the calibration source is enabled (CNFG_CAL register set to 0x700000) and connected to ECGP and ECGN (CNFG_EMUX register set to 0x0B0000). On the other hand, if the calibration source is disabled (CNFG_CAL register set to 0x000000), or if ECGP and ECGN are disconnected from the calibration signal (CNFG_EMUX register set to 0x000000), a leads-off condition is correctly detected (by reading the status register), but when the leads are connected the ECG signal is not correct, and R-to-R interval detection does not work (the RRINT interrupt is asserted at seemingly random times, and the RTOR interval read from MAX30003 appears to have random values).

Why does calibration need to be enabled in order to get a correct ECG signal and R-to-R interval detection? And why doesn't leads-off detection work if calibration is enabled? How should MAX30003 be configured to have both a reliable ECG signal and a working leads-off detection?

francescolavra, 2019-01-11:
I asked Maxim's tech support for help on this, and they replied that calibration signals and leads-off detection cannot be used at the same time. The rationale is as follows: both calibration and leads-off detection operate by adding a signal source to the input channel, so when calibration is used a leads-off condition is hard to detect because there always is an "input signal".
Since the ECG signal is usually small and easy to affect, using the calibration function is almost mandatory. As a result, the leads-off detection capability of MAX30003 is practically unusable when the frontend is being used for ECG signal sampling and R-to-R detection.
One might think of disabling dynamically the calibration function when the input signal is such that no heat beats are being detected, and enabling it again when the frontend indicates that leads are actually connected. This method can be used, however it may disrupt the R-to-R detection process if leads are connected but the ECG signal is weak, because disabling and re-enabling calibration causes significant changes in the input signal being processed by the frontend, which mess up the R-to-R detection algorithm and require the frontend to "re-synchronize" to the ECG signal, which means that at least a few seconds need to pass after switching the calibration source before the frontend has any chance of reliably detecting heart beats.

Closing this issue as it's due to intrinsic characteristics of the MAX30003 frontend.

Closed 2019-01-11.

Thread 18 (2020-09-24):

reading speed

agentff6600, 2020-09-24:
Hi!

I might have a question that seems very obvious for you. But I guess I need to ask somebody.

I have a hard time to figure out what the update speed is. When I plug in the Arduino and look at the serial monitor (or your Gui) it seems like that the data is sent in 1 sec burst.

Is that correct? How could I change that speed?

Maximum20, 2021-05-27:
Did you get it? How to change the speed?

joicetm, 2021-05-27:
Hi,

You meant the speed at which the ECG signal is streamed ?
It samples the data in every 8ms (It is configured with a sampling rate of 125 Hz), and sends it in real time. as you can see in the arduino plotter example, it sends the data serially in every 8ms.

Why do you want to increase the speed ?

Maximum20, 2021-05-27:
Sorry, I don't need to change the speed actually, I need to increase the sample rate because the signal is not detailed enough. Can I do it?

joicetm, 2021-05-28:
Yes,

It has 3 different sampling rates possible, (128, 256, 512). you can do this by writing to CNFG_ECG Register
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

There is a function in the library to set the sampling rate, call this after max30003_begin()
```
void MAX30003::max30003SetsamplingRate(uint16_t samplingRate)
```

It is not tested but you may try it out.
you will also have to adjust the delay in the loop according to the configured sampling rate.

joicetm, 2021-05-29:
fyi,

You can increase the gain also If you are looking to increase the signal quality.
The default gain in the example configuration is only 20.

Maximum20, 2021-05-29:
@joicetm I've tried MAX30003_Reg_Write(CNFG_ECG, 0x805011);
If I get right 0x8050**11** (11) mean to set ECG channel Gain to 160V/V isn't it?
I get more information from the signal but I  notice that some heart beats still don't appear on the graph .

if i use MAX30003_Reg_Write(CNFG_ECG, 0x005011);  I get more noisy signal
And what does the gain mean? How does it work?

joicetm, 2021-05-31:
No,
Its in binary, you will have to write the corresponding hex/decimal value.

Please try 0x835000 for 128 sampling rate and 160 gain.
Keep the hpf and lpf as it will help to reduce the noise.

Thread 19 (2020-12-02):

GUI closed after choosing port

RbbyWyah, 2020-12-02:
Hi there,

I have followed the schematic diagram and have programmed the modules using Arduino Uno. However, when I open the GUI and select the port. It closes immediately and gives me an error script. May I know why is this happening?

Maximum20, 2021-01-08:
I have the same problem. Please help :)

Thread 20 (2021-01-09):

Arduino UNO and Max30003 problem

Maximum20, 2021-01-09:
**Serial Port of arduino always shows me 0**. Initialization is successful as I get it right but I get only zeros in the serial port. I've tried all the three example codes and no one shows me the values opposite to 0.
 **And also photocentralview is always shutting down and creates a .log file when I press Start**. (I correctly chose the port and board name).
 What's the problem can it be?

protocentralashwin, 2021-01-09:
@Maximum20

Can you please let us know which GUI you're trying to use and which Arduino sketch is loaded on the Arduino Uno?

Also, your operating system would also help.

Maximum20, 2021-01-09:
> Can you please let us know which GUI you're trying to use and which Arduino sketch is loaded on the Arduino Uno?
> Also, your operating system would also help.

Thank you for reply. I use pc-openview-windows64 on Windows 10. I left here a log file which this GUI creates after shutting down.
I tried to use three example codes. it's ECG-stream-openview, ECG-stream-Arduino-Plotter and Computation-only. 
I use Arduino 1.8.13. 

[hs_err_pid14980.log](https://github.com/Protocentral/protocentral_max30003/files/5791414/hs_err_pid14980.log)

I made a video when I showed my issue. The link is below
https://youtu.be/aqnpOfYB1pk

protocentralashwin, 2021-01-09:
Thank you sending all the details, it looks like some kind of Java access violation with the OpenView software. We will check on this and get back to you.

Meanwhile, the other two examples, especially Arduino plotter, should print the waveform in the Arduino Serial plotter utility. Can you make sure that the baud rate there is set at 57600 and check?

Maximum20, 2021-01-09:
> Meanwhile, the other two examples, especially Arduino plotter, should print the waveform in the Arduino Serial plotter utility. Can you make sure that the baud rate there is set at 57600 and check?

Yes, of course. Here is another video, when I use it with Arduino Serial plotter. But I get 0 all the time :(
https://youtu.be/5lhlD8ywdR4

protocentralashwin, 2021-01-09:
@MohammedHM will help you out with this, first thing on Monday.

To me, at first, it looks like some connection issue (between the breakout and the Arduino). Sometimes, the wires can cause signal loss, especially for SPI data lines.

The OpenView problem and this are not related, seems like two different issues.

Maximum20, 2021-01-09:
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

Thank you for your reply. I'll wait for  @MohammedHM help so much

MohammedHM, 2021-01-11:
Hi @Maximum20, could you please share the image of your setup, interface between Arduino UNO and max30003 breakout.

Maximum20, 2021-01-11:
> Hi @Maximum20, could you please share the image of your setup, interface between Arduino UNO and max30003 breakout.

Hi. Thank you for your reply Here is it
https://imgur.com/a/kmvyv3w

SCK(SCLK) - D13
MISO - D12
MOSI - D11
CSB(CS) - D7
FCLC - D6
VCC - 3.3V
GND - GND

Maximum20, 2021-01-11:
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

joicetm, 2021-01-12:
@Maximum20 Would please remove the FCLK connection and try once. also please connect INT1 pin to D2(This is required for computation only example)

  |MAX30003 pin label| Pin Function         |Arduino Connection|
  |----------------- |:--------------------:|-----------------:|
  | MISO             | Slave Out            |  D12             |
  | MOSI             | Slave In             |  D11             |
  | SCLK             | Serial Clock         |  D13             |
  | CS               | Chip Select          |  D7              |
  | VCC              | Digital VDD          |  +5V             |
  | GND              | Digital Gnd          |  Gnd             |
  | FCLK             | 32K CLOCK            |  -               |
  | INT1             | Interrupt1           |  02              |
  | INT2             | Interrupt2           |  -               |

Maximum20, 2021-01-12:
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

@joicetm , Need I use 3.3V VCC or 5V? Doesn't it matter?

joicetm, 2021-01-12:
you should use 5V.

Maximum20, 2021-01-12:
@joicetm
I've checked if the library is 1.2.0 and it is 1.2.0.
when I'm trying to use "Example3-computation-only" I get this:

max30003 is ready
Rev ID:  80
Max30003 ID Success
Initialising the chip ...
And nothing else. When I use "Example2 stream Arduino plotter" I get the same but after "Initialising the chip ..." I get zeros in the serial port of arduino.

Here are the photos of my breakout board:
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

joicetm, 2021-01-12:
@Maximum20 where did you buy this from ?
This is not a protocentral product, i am not sure if the board has any design/hardware flaws. please contact the manufacturer for more details.

you can buy one genuine protocentral max30003 breakout  from our [website](https://protocentral.com/product/protocentral-max30003-single-lead-ecg-breakout-board-v2/).

Maximum20, 2021-01-12:
> @Maximum20 where did you buy this from ?
> This is not a protocentral product, i am not sure if the board has any design/hardware flaws. please contact the manufacturer for more details.

Oh, okay. I got it. Thank you

Closed 2021-01-12.

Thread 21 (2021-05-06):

ECGP & ECGN switches set to isolated by default

Tomisdebom, 2021-05-06:
I've been having issues with acquiring a quality signal using this library and found out that the ECGP and ECGN switches were set to isolated by default. This basically means that all electrodes you plug into the device will not be connected. You need to adjust the `CNFG_EMUX` register to make sure that both ECGP and ECGN are connected. Specifically, you can change this behaviour by changing the `max30003Begin()` function in the source file to:

```
void MAX30003::max30003Begin()
{
    max30003SwReset();
    delay(100);
    max30003RegWrite(CNFG_GEN, 0x081007);
    delay(100);
    max30003RegWrite(CNFG_EMUX,0x030000);
    delay(100);
    max30003RegWrite(CNFG_RTOR1,0x3fc600);
    max30003Synch();
    delay(100);
}

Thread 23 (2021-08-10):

Sporadic 20BPM then 240BPM

elliotglynn1, 2021-08-10:
Is there a specific set of registers that allow for the cleanest data struggling to find the issue with the rtor readings coming from the MAX30003?
At the moment everything is set to default, with calibration and leads off detection both switched off.
Any help would be greatly appreciated!

joicetm, 2021-08-11:
Hi,

I didn't fully understand your question, can you please tell me what is your exact issue?
Are you facing issues with rtor reading ? which code did you try,  Example3-Computation-only ? are you not getting the reading?

Our example arduino code is simple generic one written for demonstration purposes and on each example we have only tried to demonstrate that particular feature.

You will have to configure EN_INT and CNFG_GEN registers If you want to enable lead detection.

What do you want to do with the calibration signal? you make small chnages to the ECG-stream example make it stream the calibration signal.

elliotglynn1, 2021-08-11:
Sorry realised after I posted this it was for an arduino board and I’m not using one. I was just wondering if there was a generic set of registers to get the cleanest signal and if there was something I may have missed.

I am using the max30003 connected to a chest strap with 2 leads and the firmware is working perfectly with the calibration signal but when switched off the actual rtor readings are sporadically noisy. Also tried to change the RTOR algorithm settings but had no luck.

Thanks for all your help!

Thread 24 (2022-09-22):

Connection issue

matieu, 2022-09-22:
Hi,
I am trying to get a signal from the MAX30003. I followed the code example but I am stuck here:

Serial.println("Failed to read ID, please make sure all the pins are connected");

I spent a few hours trying to debug this with not luck.

Please see my connections in the image. (I'm using the code sample from this repo)
-Am I doing something wrong?
-Is the card working? How can I test it?

I really want to make it work. Could please help me?

Many thanks!
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

MohammedHM, 2022-09-23:
Hi Matieu,

It appears that there is a contact issue between the header and the MAX30003 breakout board. Your interface between Arduino UNO and MAX30003 via breadboard is correct.

Can you solder the headers to the pins on the MAX30003 breakout board and try uploading the example code?

matieu, 2022-09-23:
Indeed, it resolved the issue.

Thanks you so much!

Closed 2022-09-23.

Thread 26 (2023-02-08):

Arduino Mega 2560 and MAX30003 issue

vlad-roz, 2023-02-08:
I have been trying to get the MAX30003 chip to work with my Arduino MEGA and I have had no luck so far. The connections match the steps and I have downloaded the GitHub library to the Arduino IDE correctly. After verifying and compiling, it seems to say everything is fine, but I do not get any output at all that prompts the ID is correct nor any output in the OpenView program.

I would really appreciate some help or direction with the issue, thanks!

(This is was bought from the protocentral store)

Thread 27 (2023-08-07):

Failed to read ID, please make sure all the pins are connected

Killpop666, 2023-08-07:
I've connected all the pin correctly.
but showing Failed to read ID, please make sure all the pins are connected

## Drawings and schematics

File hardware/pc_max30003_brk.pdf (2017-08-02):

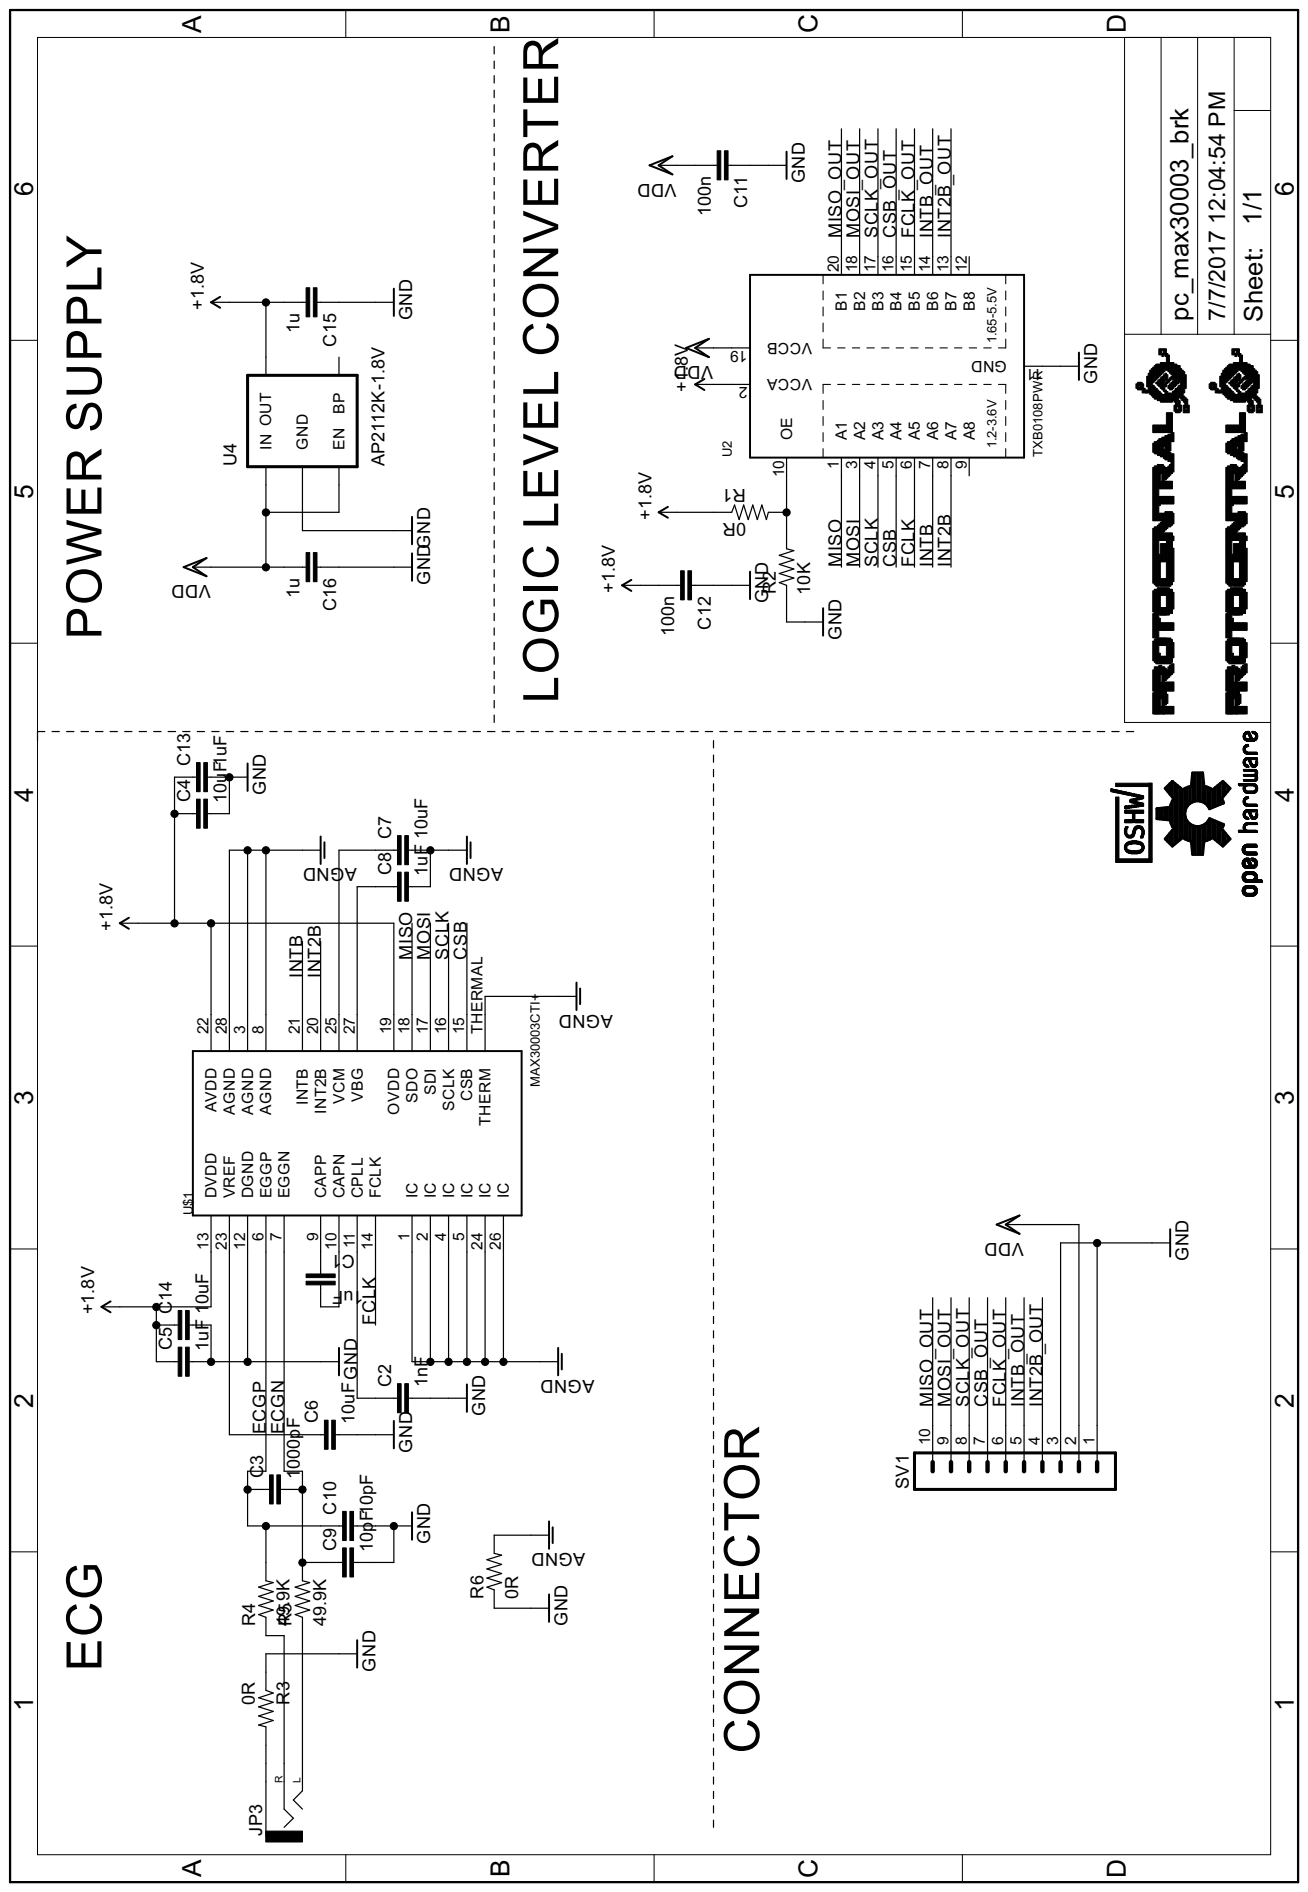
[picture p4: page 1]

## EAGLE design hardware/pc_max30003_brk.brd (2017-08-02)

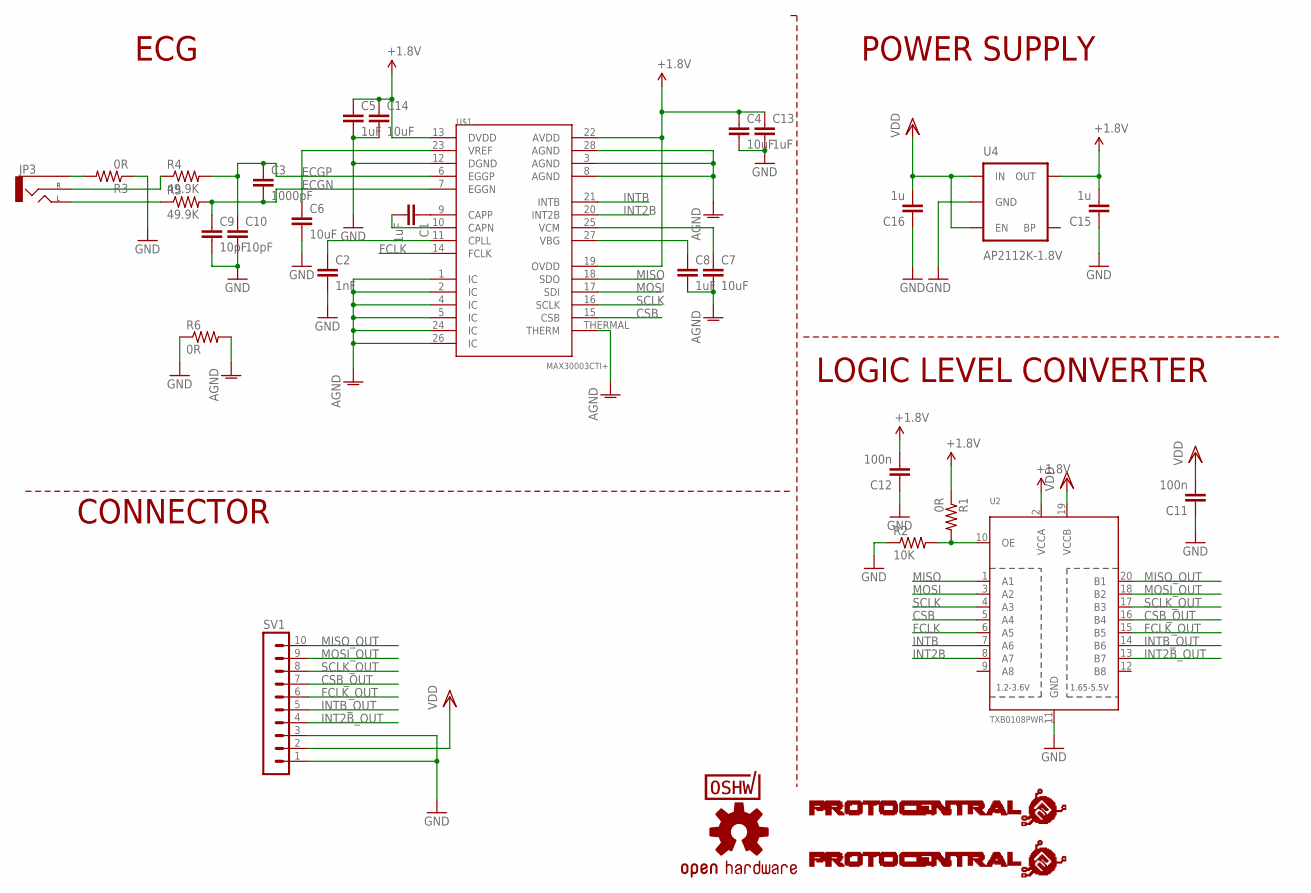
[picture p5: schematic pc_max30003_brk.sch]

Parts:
C1, C5, C8, C13: 1uF; C0805
C2: 1nF; C0805
C3: 1000pF; C0402
C4, C6, C7, C14: 10uF; C0805
C9, C10: 10pF; C0402
C11, C12: 100n; C0402
C15, C16: 1u; C0805
JP3: AUDIO-JACKSMD2; AUDIO-JACK-3.5MM-SMD
R1, R3, R6: 0R; 0805
R2: 10K; 0805
R4, R5: 49.9K; 0805
SV1: MA10-1
U2: TXB0108PWR; TSSOP20
U4: AP2112K-1.8V; SOT23-5
U$1: MAX30003CTI+; QFN-28
U$2: PROTY_LOGO_WITH_TEXT; PROTY_WITH_TEXT
U$3: PROTY-LOGO; LOGO-PROTY
U$6: OSHW-LOGOS; OSHW-LOGO-S
U$7: CERT-SMALL; CERT-SMALL-SILK

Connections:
+1.8V: C4.1, C5.1, C12.2, C13.1, C14.1, C15.2, R1.1, U2.2 (VCCA), U4.5 (OUT), U$1.13 (DVDD), U$1.19 (OVDD), U$1.22 (AVDD)
AGND: C7.2, C8.2, R6.2, U$1.1 (IC), U$1.2 (IC), U$1.3 (AGND), U$1.4 (IC), U$1.5 (IC), U$1.8 (AGND), U$1.24 (IC), U$1.26 (IC), U$1.28 (AGND), U$1.THERMAL (THERM)
CSB: U2.5 (A4), U$1.15 (CSB)
CSB_OUT: SV1.7, U2.16 (B4)
ECGN: C3.2, C9.1, R5.2, U$1.7 (EGGN)
ECGP: C3.1, C10.1, R4.2, U$1.6 (EGGP)
FCLK: U2.6 (A5), U$1.14 (FCLK)
FCLK_OUT: SV1.6, U2.15 (B5)
GND: C2.2, C4.2, C5.2, C6.2, C9.2, C10.2, C11.1, C12.1, C13.2, C14.2, C15.1, C16.1, R2.1, R3.1, R6.1, SV1.1, SV1.3, U2.11 (GND), U4.2 (GND), U$1.12 (DGND)
INT2B: U2.8 (A7), U$1.20 (INT2B)
INT2B_OUT: SV1.4, U2.13 (B7)
INTB: U2.7 (A6), U$1.21 (INTB)
INTB_OUT: SV1.5, U2.14 (B6)
MISO: U2.1 (A1), U$1.18 (SDO)
MISO_OUT: SV1.10, U2.20 (B1)
MOSI: U2.3 (A2), U$1.17 (SDI)
MOSI_OUT: SV1.9, U2.18 (B2)
unnamed: R1.2, R2.2, U2.10 (OE)
unnamed: C6.1, U$1.23 (VREF)
unnamed: C1.1, U$1.9 (CAPP)
unnamed: JP3.SLEEVE, R3.2
unnamed: C1.2, U$1.10 (CAPN)
unnamed: C2.1, U$1.11 (CPLL)
unnamed: JP3.TIP (LEFT), R5.1
unnamed: JP3.RING (RIGHT), R4.1
unnamed: C7.1, U$1.25 (VCM)
unnamed: C8.1, U$1.27 (VBG)
SCLK: U2.4 (A3), U$1.16 (SCLK)
SCLK_OUT: SV1.8, U2.17 (B3)
VDD: C11.2, C16.2, SV1.2, U2.19 (VCCB), U4.1 (IN), U4.3 (EN)

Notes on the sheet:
ECG
POWER SUPPLY
LOGIC LEVEL CONVERTER
CONNECTOR

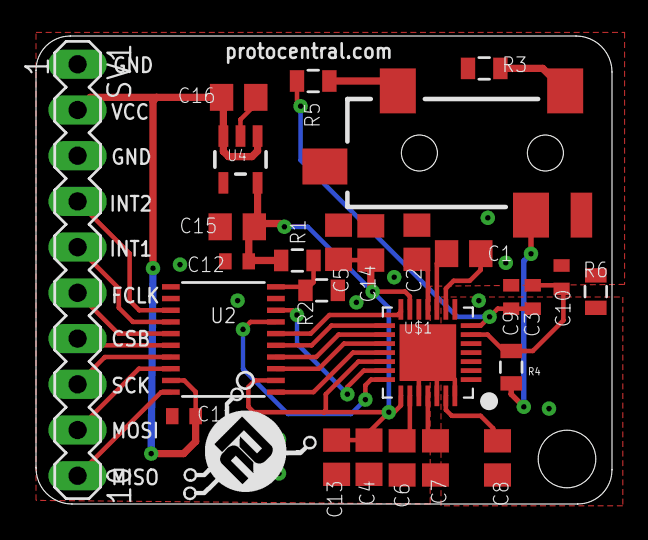
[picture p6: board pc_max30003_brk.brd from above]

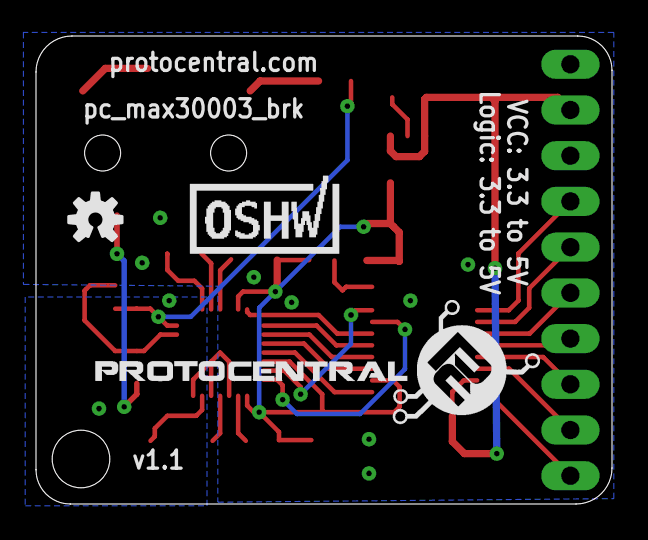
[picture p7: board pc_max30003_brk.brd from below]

Board: 4 copper layers, 32.0 x 26.0 mm, 31 parts (3 on the bottom side), 30 nets.

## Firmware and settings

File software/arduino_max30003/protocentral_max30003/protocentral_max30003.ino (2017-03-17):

#include<SPI.h>
#include <TimerOne.h>
#include "MAX30003.h"

#define ADS1292_CS_PIN   7
#define CLK_PIN          6

volatile char SPI_RX_Buff[5] ;
volatile char *SPI_RX_Buff_Ptr;
int i=0;
unsigned long uintECGraw = 0;
signed long intECGraw=0;
uint8_t DataPacketHeader[15];
uint8_t data_len = 8;

char SPI_temp_32b[4];
char SPI_temp_Burst[100];

// 32KHz clock using timer1
void timerIsr()
{
    digitalWrite( CLK_PIN, digitalRead(CLK_PIN ) ^ 1 ); // toggle Digital6 attached to FCLK  of MAX30003
}

void setup() 
{
    Serial.begin(115200); //Serial begin
    
    pinMode(ADS1292_CS_PIN,OUTPUT);
    digitalWrite(ADS1292_CS_PIN,HIGH); //disable device

    SPI.begin();
    SPI.setBitOrder(MSBFIRST); 
    //CPOL = 0, CPHA = 0
    SPI.setDataMode(SPI_MODE0);
    // Selecting 1Mhz clock for SPI
    SPI.setClockDivider(SPI_CLOCK_DIV4);
    
    pinMode(CLK_PIN,OUTPUT);

    MAX30003_begin();   // initialize MAX30003
    
}

void loop() 
{
    MAX30003_Reg_Read(ECG_FIFO);

    unsigned long data0 = (unsigned long) (SPI_temp_32b[0]);
    data0 = data0 <<24;
    unsigned long data1 = (unsigned long) (SPI_temp_32b[1]);
    data1 = data1 <<16;
    unsigned long data2 = (unsigned long) (SPI_temp_32b[2]);
    data2 = data2 >>6;
    data2 = data2 & 0x03;
    
    unsigned long data = (unsigned long) (data0 | data1 | data2);
    signed long sdata = (signed long) (data);

    MAX30003_Reg_Read(RTOR);
    unsigned int RTOR_msb = (unsigned int) (SPI_temp_32b[0]);
    RTOR_msb = RTOR_msb <<8;
    unsigned int RTOR_lsb = (unsigned int) (SPI_temp_32b[1]);

    unsigned int rtor = (RTOR_msb | RTOR_lsb);
    rtor = rtor >>2 ;
  
    float rr =  60000000 /((float)rtor*8); 
    long hr = (long)rr;
    
  //  Serial.println(hr);
  //  Serial.print(",");
   // Serial.println(hr);
      

      DataPacketHeader[0] = 0x0A;
      DataPacketHeader[1] = 0xFA;
      DataPacketHeader[2] = 0x08;
      DataPacketHeader[3] = 0;
      DataPacketHeader[4] = 0x02;
    

      DataPacketHeader[5] = sdata;
      DataPacketHeader[6] = sdata>>8;
      DataPacketHeader[7] = sdata>>16;
      DataPacketHeader[8] = sdata>>24; 
   
      DataPacketHeader[9] = hr;
      DataPacketHeader[10] = hr>>8;
      DataPacketHeader[11] = hr>>16;
      DataPacketHeader[12] = hr>>24; 
  
      DataPacketHeader[13] = 0x00;
      DataPacketHeader[14] = 0x0b;
  
      for(i=0; i<15; i++) // transmit the data
      {
        Serial.write(DataPacketHeader[i]);
  
       }    

    delay(1);      
}

void MAX30003_Reg_Write (unsigned char WRITE_ADDRESS, unsigned long data)
{
 
  // now combine the register address and the command into one byte:
   byte dataToSend = (WRITE_ADDRESS<<1) | WREG;

   // take the chip select low to select the device:
   digitalWrite(ADS1292_CS_PIN, LOW);
   
   delay(2);
   SPI.transfer(dataToSend);   //Send register location
   SPI.transfer(data>>16);     //number of register to wr
   SPI.transfer(data>>8);      //number of register to wr
   SPI.transfer(data);      //Send value to record into register
   delay(2);
   
   // take the chip select high to de-select:
   digitalWrite(ADS1292_CS_PIN, HIGH);
}

void max30003_sw_reset(void)
{
  MAX30003_Reg_Write(SW_RST,0x000000);     
  delay(100);
}

void max30003_synch(void)
{
  MAX30003_Reg_Write(SYNCH,0x000000);
}

void MAX30003_Reg_Read(uint8_t Reg_address)
{
   uint8_t SPI_TX_Buff;
 
   digitalWrite(ADS1292_CS_PIN, LOW);
  
   SPI_TX_Buff = (Reg_address<<1 ) | RREG;
   SPI.transfer(SPI_TX_Buff); //Send register location
   
   for ( i = 0; i < 3; i++)
   {
      //SPI_RX_Buff[i] = SPI.transfer(0xff);
      SPI_temp_32b[i] = SPI.transfer(0xff);
   }

   digitalWrite(ADS1292_CS_PIN, HIGH);
}

void MAX30003_Read_Data(int num_samples)
{
  uint8_t SPI_TX_Buff;

  digitalWrite(ADS1292_CS_PIN, LOW);   

  SPI_TX_Buff = (ECG_FIFO_BURST<<1 ) | RREG;
  SPI.transfer(SPI_TX_Buff); //Send register location

  for ( i = 0; i < num_samples*3; ++i)
  {
    SPI_temp_Burst[i] = SPI.transfer(0x00);
  }
  
  digitalWrite(ADS1292_CS_PIN, HIGH);  
}


void MAX30003_begin()
{
    //Start CLK timer
    Timer1.initialize(16);              // set a timer of length 100000 microseconds (or 0.1 sec - or 10Hz => the led will blink 5 times, 5 cycles of on-and-off, per second)
    Timer1.attachInterrupt( timerIsr ); // attach the service routine here
    
    //SW Reset
    max30003_sw_reset();
    delay(100);

    MAX30003_Reg_Write(CNFG_GEN, 0x081003);
    delay(100);
    //Put the chip in CAL mode
    MAX30003_Reg_Write(CNFG_CAL, 0x700000);
    delay(100);
    MAX30003_Reg_Write(CNFG_EMUX,0x0B0000);
   
    //MAX30003_Reg_Write(CNFG_EMUX,0x000000);
    delay(100);

    MAX30003_Reg_Write(CNFG_ECG, 0x805000);
    delay(100);

    
    MAX30003_Reg_Write(CNFG_RTOR1,0x3fc600);
    max30003_synch();
    delay(100);
}

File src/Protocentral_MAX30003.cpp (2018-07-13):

#include "Protocentral_MAX30003.h" 
#include <SPI.h>
#include <TimerOne.h>

uint8_t global_fclk ;
    //<<constructor>> 
Protocentral_MAX30003::Protocentral_MAX30003(){
}
     
    //<<destructor>>
Protocentral_MAX30003::~Protocentral_MAX30003(){/*nothing to destruct*/}

void timerIsr(void)
{
  digitalWrite( global_fclk, digitalRead(global_fclk ) ^ 1 ); // toggle Digital6 attached to FCLK  of MAX30003
}
  
bool Protocentral_MAX30003::begin(uint8_t cs_pin, uint8_t fclk_pin)
{
  m_fclk_pin = fclk_pin;
  global_fclk = fclk_pin;
  m_cs_pin = cs_pin;

  pinMode(m_cs_pin,OUTPUT);
  digitalWrite(m_cs_pin,HIGH); //disable device

  SPI.begin();
  SPI.setBitOrder(MSBFIRST); 
  SPI.setDataMode(SPI_MODE0);
  SPI.setClockDivider(SPI_CLOCK_DIV4);
  
  pinMode(m_fclk_pin,OUTPUT);

  Timer1.initialize(16);              // set a timer of length 100000 microseconds (or 0.1 sec - or 10Hz => the led will blink 5 times, 5 cycles of on-and-off, per second)
  Timer1.attachInterrupt( timerIsr ); // attach the service routine here
  
/*  //read the chip id
  if(!(Read_ID())){
    return false;
  }
*/
  SW_Reset();
  delay(100);
  Reg_Write(CNFG_GEN, 0x080004);
  delay(100);
  Reg_Write(CNFG_CAL, 0x720000);  // 0x700000  
  delay(100);
  Reg_Write(CNFG_EMUX,0x000000);
  delay(100);
  Reg_Write(CNFG_ECG, 0x401000);  // d23 - d22 : 10 for 250sps , 00:500 sps
  delay(100);

  Reg_Write(CNFG_RTOR1,0x3fc600);
  Synch();
  delay(100);

  Reg_Write(FIFO_RST,0x000000);

  return true;
}

void Protocentral_MAX30003::SW_Reset(void)
{
  Reg_Write(SW_RST,0x000000);     
  delay(100);
}

void Protocentral_MAX30003::Synch(void)
{
  Reg_Write(SYNCH,0x000000);
}

void Protocentral_MAX30003::Reg_Write (uint8_t WRITE_ADDRESS, unsigned long data)
{
 
  // now combine the register address and the command into one byte:
   byte dataToSend = (WRITE_ADDRESS<<1) | WREG;

   // take the chip select low to select the device:
   digitalWrite(m_cs_pin, LOW);
   
   delay(2);
   SPI.transfer(dataToSend);   //Send register location
   SPI.transfer(data>>16);     //number of register to wr
   SPI.transfer(data>>8);      //number of register to wr
   SPI.transfer(data);      //Send value to record into register
   delay(2);
   
   // take the chip select high to de-select:
    digitalWrite(m_cs_pin, HIGH);
}

void Protocentral_MAX30003::Read_Data(int num_samples)
{
  uint8_t SPI_TX_Buff;

  digitalWrite(m_cs_pin, LOW);   

  SPI_TX_Buff = (ECG_FIFO_BURST<<1 ) | RREG;
  SPI.transfer(SPI_TX_Buff); //Send register location

  for ( i = 0; i < num_samples*3; ++i)
  {
    SPI_temp_Burst[i] = SPI.transfer(0x00);
  }
  
  digitalWrite(m_cs_pin, HIGH);  
}

void Protocentral_MAX30003::send_data_serial(void)
{
  unsigned long data0 = (unsigned long) (SPI_temp_32b[0]);
  data0 = data0 <<24;
  unsigned long data1 = (unsigned long) (SPI_temp_32b[1]);
  data1 = data1 <<16;
  unsigned long data2 = (unsigned long) (SPI_temp_32b[2]);
  data2 = data2 & 0xc0;
  data2 = data2 << 8;
  data = (unsigned long) (data0 | data1 | data2);
  ecgdata = (signed long) (data);

  DataPacketHeader[0] = 0x0A;
  DataPacketHeader[1] = 0xFA;
  DataPacketHeader[2] = 0x0C;
  DataPacketHeader[3] = 0;
  DataPacketHeader[4] = 0x02;

  DataPacketHeader[5] = ecgdata;
  DataPacketHeader[6] = ecgdata>>8;
  DataPacketHeader[7] = ecgdata>>16;
  DataPacketHeader[8] = ecgdata>>24; 

  DataPacketHeader[9] =  0;
  DataPacketHeader[10] = 0;
  DataPacketHeader[11] = 0x00;
  DataPacketHeader[12] = 0x00; 

  DataPacketHeader[13] = 0;
  DataPacketHeader[14] = 0;
  DataPacketHeader[15] = 0x00;
  DataPacketHeader[16] = 0x00;

  DataPacketHeader[17] = 0x00;
  DataPacketHeader[18] = 0x0b;

  for(i=0; i<19; i++) // transmit the data
  {
    Serial.write(DataPacketHeader[i]);
  }

}

void Protocentral_MAX30003::Set_SamplingRate(uint8_t sampling_rate){

  Reg_Read(CNFG_ECG);
  Serial.println(SPI_temp_32b[1]);
  reg_write_value = SPI_temp_32b[1] & ECG_CONFIG_SRMASK;
  reg_write_value |= sampling_rate;

  Reg_Write(CNFG_ECG, sampling_rate);
}

bool Protocentral_MAX30003::Read_ID(void){

  Reg_Read(STATUS);

  if(SPI_temp_32b[1] == 0x51)
  {
    return true;
  }
  else
  {
    return false;
  }
}

void Protocentral_MAX30003::Reg_Read(uint8_t Reg_address)
{
  uint8_t SPI_TX_Buff;
  digitalWrite(m_cs_pin, LOW);
  
  SPI_TX_Buff = (Reg_address<<1 ) | RREG;
  SPI.transfer(SPI_TX_Buff); //Send register location
   
  for ( i = 0; i < 3; i++)
  {
    SPI_temp_32b[i] = SPI.transfer(0xff);
  }
  Serial.println(SPI_temp_32b[1]);
  digitalWrite(m_cs_pin, HIGH);
}

 void Protocentral_MAX30003::Stream_ECG(void){

  while(FIFO_EMPTY){

    Reg_Read(STATUS);
    uint8_t status_bits = (SPI_temp_32b[0] >> 4) & 0xF;
    
    if ((status_bits & 0x4) == 0x4) {

      Serial.println("FIFO Reset");
      Reg_Write(FIFO_RST,0x000000);
      
    }
    else if ((status_bits & 0x8) == 0) {
        // No data present in FIFO
      Serial.println("no data in FIFO ");
    }
    else{
      FIFO_EMPTY = false;
    }
  }

  for (i=0; i <SAMPLES_PER_PACKET; i++) {

    Reg_Read(ECG_FIFO);
    send_data_serial();
  }

  FIFO_EMPTY = true;
  delayMicroseconds(1);
}

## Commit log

2017-03-10 Reorganized structure, edited Readme.md
    [pc_max30003_brk.brd, pc_max30003_brk.sch]
2017-08-02 updated design file
    [pc_max30003_brk.brd, pc_max30003_brk.sch]
2017-08-02 upadted readme
    [pc_max30003_brk.brd, pc_max30003_brk.sch]
2017-08-02 added v1.1 design files
    [pc_max30003_brk.brd, pc_max30003_brk.sch]

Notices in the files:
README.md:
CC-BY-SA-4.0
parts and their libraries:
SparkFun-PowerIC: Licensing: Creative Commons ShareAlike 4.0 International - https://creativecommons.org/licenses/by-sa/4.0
